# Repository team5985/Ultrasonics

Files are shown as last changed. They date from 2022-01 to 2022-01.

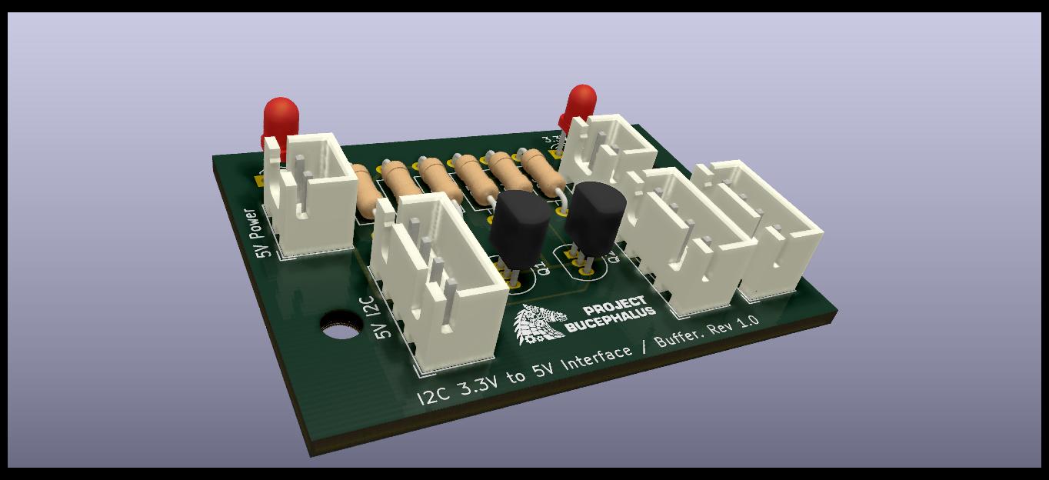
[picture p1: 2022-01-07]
I2C_Interface/V01.01/I2C_Interface.jpg

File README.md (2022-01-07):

# Ultrasonics
Ultrasonic hardware and software

This contains the design files for the ultrasonics circuit boards, as well as the software for the microcontroller.

* Hardware
These are the project files from KiCAD and include the circuit diagramme, netlist, and PCB layout. The Gerber directory
contains the final output that was sent to the PCB manufacturer to have the boards made. This should be openable as a
project from within KiCAD.

* Software
These are the project files from AVR Studio (or ATMEL Studio, or Microchip Studio) and contain the setup required to
compile, emulate and debug the microcontroller code. This should be able to be opened by AVR Studio as a project and
used immediately. The main file in this is "main.asm" which is the actual code for the microcontroller, the remaining
files are merely configuration.

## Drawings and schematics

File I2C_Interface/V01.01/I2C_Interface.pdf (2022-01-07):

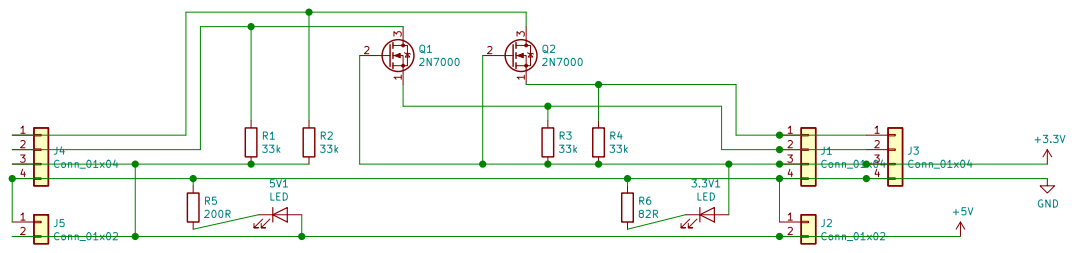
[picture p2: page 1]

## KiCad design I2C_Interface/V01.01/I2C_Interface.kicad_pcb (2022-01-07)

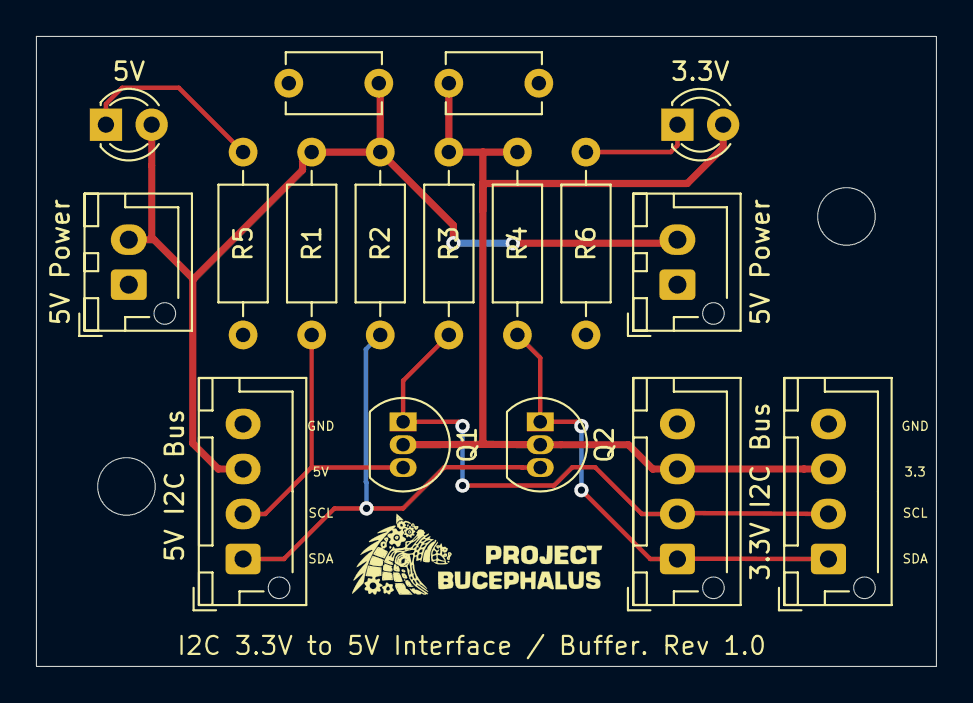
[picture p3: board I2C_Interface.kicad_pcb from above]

Board: 2 copper layers, 50.0 x 35.0 mm, 17 parts (0 on the bottom side), 9 nets.

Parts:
3.3V, 5V: LED; LED_D3.0mm
C1, C2: 4.7uF; C_Disc_D5.1mm_W3.2mm_P5.00mm
J1, J3: 3.3V I2C Bus; JST_XH_B4B-XH-AM_1x04_P2.50mm_Vertical
J2, J5: 5V Power; JST_XH_B2B-XH-AM_1x02_P2.50mm_Vertical
J4: 5V I2C Bus; JST_XH_B4B-XH-AM_1x04_P2.50mm_Vertical
Q1, Q2: 2N7000; TO-92_Inline
R1, R2, R3, R4: 33k; R_Axial_DIN0207_L6.3mm_D2.5mm_P10.16mm_Horizontal
R5: 200R; R_Axial_DIN0207_L6.3mm_D2.5mm_P10.16mm_Horizontal
R6: 82R; R_Axial_DIN0207_L6.3mm_D2.5mm_P10.16mm_Horizontal

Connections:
+3V3: 3.3V.2, C2.1, J1.3, J3.3, Q1.2, Q2.2, R3.2, R4.2
+5V: 5V.2, C1.2, J2.2, J4.3, J5.2, R1.2, R2.2
GND: C1.1, C2.2, J1.4, J2.1, J3.4, J4.4, J5.1, R5.1, R6.1
unnamed: 3.3V.1, R6.2
unnamed: 5V.1, R5.2
unnamed: J1.1, J3.1, Q2.1, R4.1
unnamed: J1.2, J3.2, Q1.1, R3.1
unnamed: J4.1, Q2.3, R2.1
unnamed: J4.2, Q1.3, R1.1

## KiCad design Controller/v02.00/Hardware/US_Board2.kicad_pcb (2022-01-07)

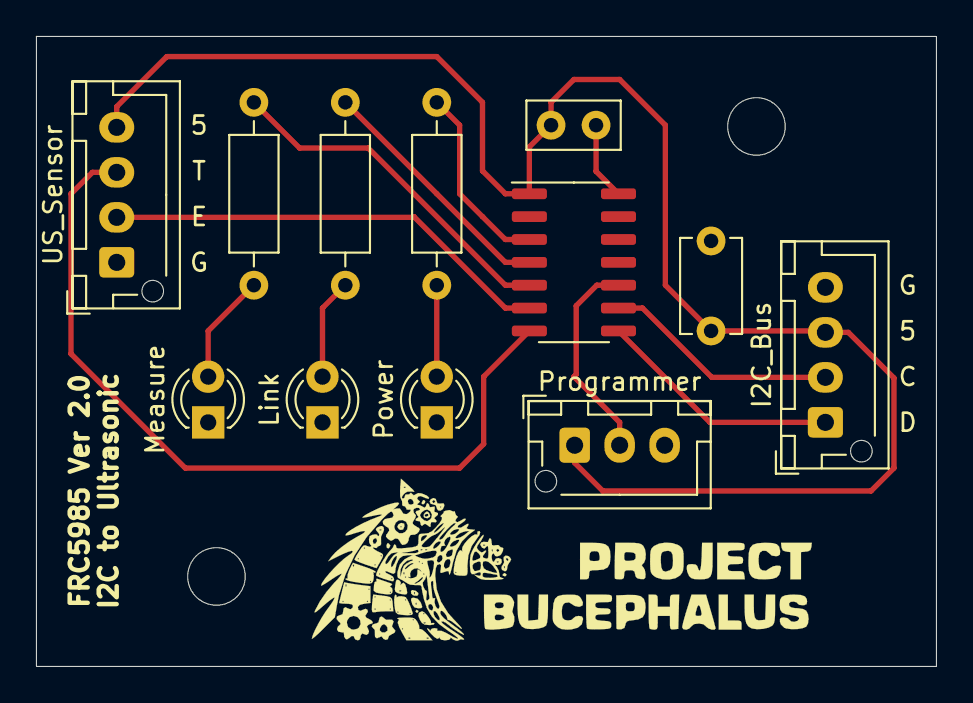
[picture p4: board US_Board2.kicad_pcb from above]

Board: 2 copper layers, 50.0 x 35.0 mm, 12 parts (0 on the bottom side), 13 nets.

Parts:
200R1, 200R2, 200R3: R; R_Axial_DIN0207_L6.3mm_D2.5mm_P10.16mm_Horizontal
C1: 4.7uF; C_Disc_D5.1mm_W3.2mm_P5.00mm
C2: 100nF; C_Disc_D5.0mm_W2.5mm_P2.50mm
I2C_Bus: Conn_01x04_Male; JST_XH_B4B-XH-AM_1x04_P2.50mm_Vertical
Link: Yellow LED; LED_D3.0mm
Measure: Green LED; LED_D3.0mm
Power: Red LED; LED_D3.0mm
Programmer: Conn_01x03; JST_XH_B3B-XH-AM_1x03_P2.50mm_Vertical
U1: ATtiny214-SS; SOIC-14_3.9x8.7mm_P1.27mm
US_Sensor: Conn_01x04_Male; JST_XH_B4B-XH-AM_1x04_P2.50mm_Vertical

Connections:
+5V: C1.1, C2.1, I2C_Bus.3, Programmer.1, U1.1, US_Sensor.4
GND: C1.2, C2.2, I2C_Bus.4, Link.1, Measure.1, Power.1, Programmer.3, U1.14, US_Sensor.1
unnamed: 200R1.1, Link.2
unnamed: 200R1.2, U1.4
unnamed: 200R2.1, Power.2
unnamed: 200R2.2, U1.3
unnamed: 200R3.1, Measure.2
unnamed: 200R3.2, U1.5
unnamed: I2C_Bus.1, U1.8
unnamed: I2C_Bus.2, U1.9
unnamed: Programmer.2, U1.10
unnamed: U1.6, US_Sensor.2
unnamed: U1.7, US_Sensor.3

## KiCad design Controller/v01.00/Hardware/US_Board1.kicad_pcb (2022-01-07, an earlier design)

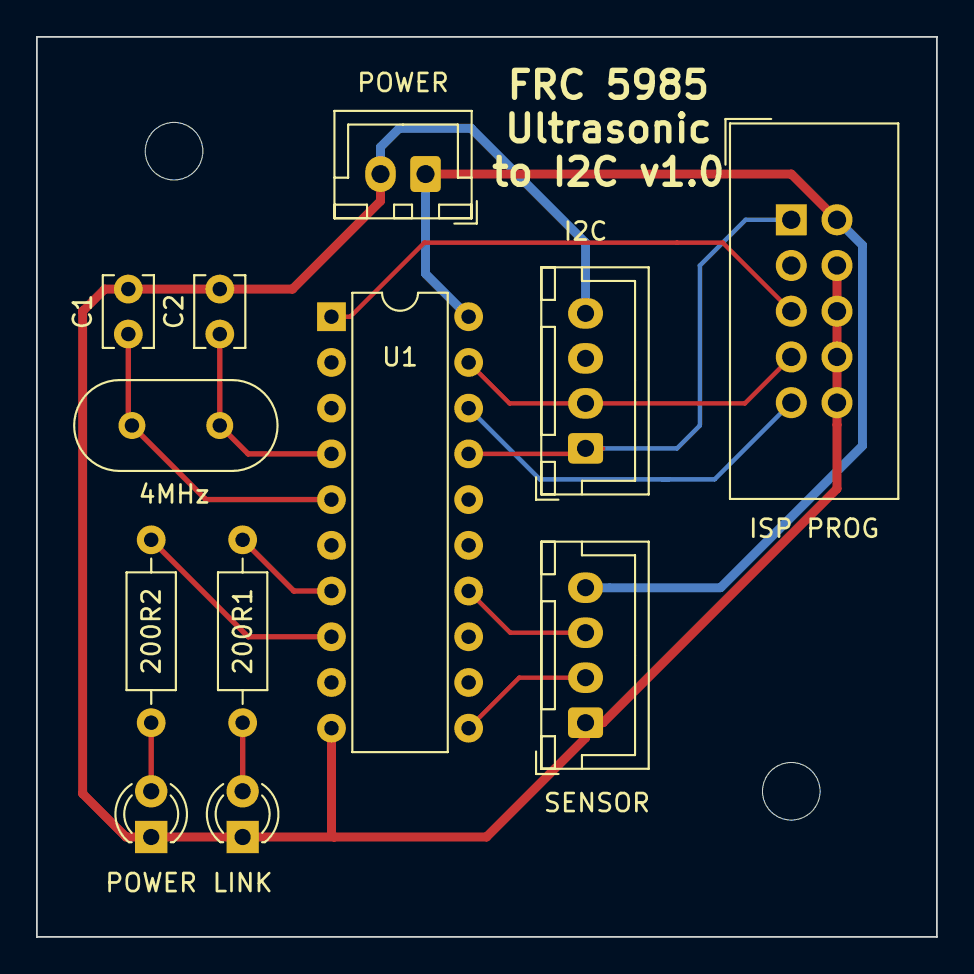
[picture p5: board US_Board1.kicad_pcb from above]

Board: 2 copper layers, 50.0 x 50.0 mm, 14 parts (0 on the bottom side), 14 nets.

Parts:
4MHz: Crystal; Crystal_HC49-U_Vertical
200R1, 200R2: R; R_Axial_DIN0207_L6.3mm_D2.5mm_P10.16mm_Horizontal
 : MountingHole_3.2mm_M3_DIN965
 #2: MountingHole_3.2mm_M3_DIN965
C1, C2: C; C_Disc_D3.8mm_W2.6mm_P2.50mm
I2C: Conn_01x04_Male; JST_XH_B4B-XH-A_1x04_P2.50mm_Vertical
ISP PROG: AVR-ISP-10; IDC-Header_2x05_P2.54mm_Vertical
LINK: Yellow LED; LED_D3.0mm
POWER: Conn_01x02_Male; JST_XH_B2B-XH-A_1x02_P2.50mm_Vertical
POWER#2: Red LED; LED_D3.0mm
SENSOR: Conn_01x04_Male; JST_XH_B4B-XH-A_1x04_P2.50mm_Vertical
U1: ATtiny2313-20PU; DIP-20_W7.62mm

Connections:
+5V: ISP PROG.2, POWER.1, SENSOR.4, U1.20
GND: C1.2, C2.2, I2C.4, ISP PROG.4, ISP PROG.6, ISP PROG.8, ISP PROG.10, LINK.1, POWER.2, POWER#2.1, SENSOR.1, U1.10
unnamed: 4MHz.1, C1.1, U1.5
unnamed: 4MHz.2, C2.1, U1.4
unnamed: 200R1.1, LINK.2
unnamed: 200R1.2, U1.7
unnamed: 200R2.1, POWER#2.2
unnamed: 200R2.2, U1.8
unnamed: I2C.1, ISP PROG.1, U1.17
unnamed: I2C.2, ISP PROG.7, U1.19
unnamed: ISP PROG.5, U1.1
unnamed: ISP PROG.9, U1.18
unnamed: SENSOR.2, U1.11
unnamed: SENSOR.3, U1.14

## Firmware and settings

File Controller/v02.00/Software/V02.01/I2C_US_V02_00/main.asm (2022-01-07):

;
; I2C_US_V02_00.asm
;
; Created: 4/02/2021 10:20:44 PM
; Author : Graham
;
; Device = ATtiny214
;
; Code for I2C to Ultrasonic interface.
; Hardware version v2.0
; (not supported on hardware version v1.0)
;
; Internal 20MHz clock is selected
; Timer A0 - Sends pulses to the ultrasonic sensor
; - Pin 7 - WO2/PB2
; Timer B0 is uses to measure the length of the returning pulses.
; - Pin 6 - PB3
; I2C interface
; - Pin 8 - SDA/PB1
; - Pin 9 - SCL/PB0
; LED Outputs
; - Pin 3 - PA5 - Red LED (Power)
; - Pin 4 - PA6 - Yellow (Comms)
; - Pin 5 - PA7 - Green (Valid Measurement)
; Overhead connections...
; - Pin 1 - VDD +5v
; - Pin 14 - GND
; - Pin 10 - UPDI programming interface
; Unused pins
; - Pin 2 - PA4
; - Pin 11 - PA1
; - Pin 12 - PA2
; - Pin 13 - PA3

.include "tn214def.inc"

; Change this address on some devices to have multiple addressable devices on a single I2C bus.
.equ MySlaveAddress	= 0x14

.equ DDR_I2C	= PORTB_DIR
.equ PORT_I2C	= PORTB_OUT
.equ PIN_I2C	= PORTB_IN
.equ SCL		= 0				;!!!!!!!!!!!!!SCL DDR and PORT are ALWAYS =1	 !!!!!!!!!!!!!!!!!
.equ SDA 		= 1				;!!!!!!!!!!!!!SDA PORT are ALWAYS =1 			!!!!!!!!!!!!!!!!!
.equ OC1A		= 3				; Output compare pin for ultrasonic trigger
.equ LED_RED	= 5
.equ LED_YELLOW	= 6
.equ LED_GREEN	= 7

.def AL = r16
.equ TCA0_WO2 = 2				; WO2 is portB pin 2

	; If we set the prescaler at /24 then we end up with 0.833MHz = 78.6ms / 65536 counts
	;	This gives 50000 counts per 60ms.
	;	The pulse needs to be on for 9 counts to be greater than 10us
.equ TCA0_PERIOD = 50000
.equ TCA0_PWMONTIME = 10

.dseg
.org	SRAM_START					;RAMTOP
I2CsubAddrBuf:	 	.byte 1

;****************************************************************************************
;----------------------------------------------------------;
.cseg
.org 0x0000
	rjmp RESET
.org CRCSCAN_NMI_vect
	rjmp ISR
.org BOD_VLM_vect
	rjmp ISR
.org PORTA_PORT_vect
	rjmp ISR
.org PORTB_PORT_vect
	rjmp ISR
.org RTC_CNT_vect
	rjmp ISR
.org RTC_PIT_vect
	rjmp ISR
.org TCA0_OVF_vect		; Also TCA0_LUNF
	rjmp TCA0_OVF_ISR
.org TCA0_HUNF_vect
	rjmp ISR
.org TCA0_LCMP0_vect		; Also TCA0_CMP0
	rjmp ISR
.org TCA0_LCMP1_vect		; Also TCA0_CMP1
	rjmp ISR
.org TCA0_LCMP2_vect		; Also TCA0_CMP2
	rjmp ISR
.org TCB0_INT_vect
	rjmp TCB0_INT_ISR
.org TCD0_OVF_vect
	rjmp ISR
.org TCD0_TRIG_vect
	rjmp ISR
.org AC0_AC_vect
	rjmp ISR
.org ADC0_RESRDY_vect
	rjmp ISR
.org ADC0_WCOMP_vect
	rjmp ISR
.org TWI0_TWIS_vect
	rjmp TWI0_TWIS_ISR
.org TWI0_TWIM_vect
	rjmp TWI0_TWIM_ISR
.org SPI0_INT_vect
	rjmp ISR
.org USART0_RXC_vect
	rjmp ISR
.org USART0_DRE_vect
	rjmp ISR
.org USART0_TXC_vect
	rjmp ISR
.org NVMCTRL_EE_vect
	rjmp ISR


RESET:

	;It is not required to initialise the stack pointer.
	;ldi r16, low(RAMEND)
	;out SPL, r16

	;set port A pins 5, 6 & 7 to outputs for the LEDs, remainder as inputs/tristate.
	ldi r16, 0x00+(1<<LED_RED)+(1<<LED_YELLOW)+(1<<LED_GREEN)
	sts PORTA_DIR, r16

	ldi r16, 0x00+(1<<LED_RED)+(0<<LED_YELLOW)+(0<<LED_GREEN)
	sts PORTA_OUT, r16

	; I2C clock line, plus PWM pin are outputs
	ldi r16, 0x00+(1<<SCL)+(1<<TCA0_WO2)
	sts PORTB_DIR, r16
	ldi r16, 0x00+(1<<SCL)+(1<<SDA)
	sts PORTB_OUT, r16

	;The analogue comparator is disabled on startup already
	;sbi ACSR,ACD					;disable analogue comparator
	
	;Not sure what to do here - need to read the manual!
	;outi MCUCR,(1<<SE)				;Sleep On///Power-Down Mode

	;This next few lines fills the first 120 bytes of the buffer used for I2C with numbers counting up.
	;It can be used for testing before the ultrasonic code is finished.
	;It will be overwritten as soon as an ultrasonic measurement is made.
	ldi XL,low(I2CsubAddrBuf)
	ldi XH,high(I2CsubAddrBuf)
	ldi r16,1
initloop1:
	st X+,r16
	inc r16
	cpi r16,120
	brlo initloop1


	;Initialise timer/counter 0
	; TCA0 will drive the hardware pin to trigger an ultrasonic measure.
	; To pulse approximately every 60ms, pulse length at least 10us
	; Also an interrupt to be generated to reset the I2C link LED

	ldi r16, CPU_CCP_IOREG_gc
	ldi r17, 0x00 + (1<<CLKCTRL_PEN_bp) + CLKCTRL_PDIV_24X_gc
	sts CPU_CCP, r16		; Unlock clock controller for change.
	sts CLKCTRL_MCLKCTRLB, r17

	; Set clock period to 50000 counts.
	ldi r16, low(TCA0_PERIOD)
	sts TCA0_SINGLE_PER, r16
	ldi r16, high(TCA0_PERIOD)
	sts TCA0_SINGLE_PER+1, r16

	;Set WO2/CMP2 on time to 10 counts
	ldi r16, low(TCA0_PWMONTIME)
	sts TCA0_SINGLE_CMP2, r16
	ldi r16, high(TCA0_PWMONTIME)
	sts TCA0_SINGLE_CMP2+1, r16

	; Enable counter in normal mode
	ldi r16, (1<<TCA_SINGLE_ENABLE_bp)
	sts TCA0_SINGLE_CTRLA, r16

	; Enable waveform on CMP2 in PWM mode
	ldi r16, (1<<TCA_SINGLE_CMP2EN_bp) + (TCA_SINGLE_WGMODE_SINGLESLOPE_gc <<TCA_SINGLE_WGMODE_gp)
	sts TCA0_SINGLE_CTRLB, r16

	; Enable overflow interrupt.
	ldi r16, (1<<TCA_SINGLE_OVF_bp)
	sts TCA0_SINGLE_INTCTRL, r16




	;Initialise timer/counter 1
	;Normal counter mode, no output compare
;	outi TCCR1A, 0
	; Clock select / 8
;	outi TCCR1B, (1<<CS11) | (1<<ICES1)
	;outi TCCR1B, (1<<CS10) | (1<<CS11)

	ldi r16, (1<<TCB_ENABLE_bp)
	sts TCB0_CTRLA, r16
	ldi r16, (1<<TCB_CCMPEN_bp) + (TCB_CNTMODE_PW_gc<<TCB_CNTMODE_gp)
	ldi r16, (TCB_CNTMODE_PW_gc<<TCB_CNTMODE_gp)
	sts TCB0_CTRLB, r16
	ldi r16, (1<<TCB_CAPTEI_bp)
	sts TCB0_EVCTRL, r16
	ldi r16, (1<<TCB_CAPT_bp)
	sts TCB0_INTCTRL, r16

	ldi r16, EVSYS_ASYNCCH1_PORTB_PIN3_gc
	sts EVSYS_ASYNCCH1, r16
	ldi r16, EVSYS_ASYNCUSER0_ASYNCCH1_gc
	sts EVSYS_ASYNCUSER0, r16


;I2Cinit:

	; Enable the TWI as an I2C slave by writing in our slave address and enabling.
	ldi r16, MySlaveAddress<<1
	sts TWI0_SADDR, r16
	ldi r16, 0x00 + (1<<TWI_ENABLE_bp) + (1<<TWI_DIEN_bp) + (1<<TWI_APIEN_bp) + (1<<TWI_PIEN_bp) + (1<<TWI_SMEN_bp)
	sts TWI0_SCTRLA, r16

	sei

MainLoop:
;	sleep
;	WDR
	rjmp MainLoop


; TWI slave interrupt
; if APIF (address or stop) bit on
;	if AP is on (address interrupt)
;		if R/W bit is off (write)
;		- remember write mode
;		- reset APIF flag
;		- return
;		else (read)
;		- remember read mode
;		- initialise read pointer
;		- reset APIF flag
;		- return
;	else (STOP command)
;	- reset all read / write flags
; else if DIF is on (data transaction complete)
;	if reading
;	- get next byte & increment pointer
;	- write byte
;	- clear DIF flag
;	- return
;	else (writing)
;	- read and discard byte
;	- clear DIF flag
;	- return
TWI0_TWIS_ISR:
	cli
	lds r17, TWI0_SSTATUS
	sbrs r17, TWI_APIF_bp
	rjmp TWI0_NO_APIF
	; APIF flag is on (address or stop interrupt)
	sbrs r17, TWI_AP_bp
	rjmp TWI0_STOP
	; AP flag is on (address interrupt)
	lds r17, TWI0_SDATA
	sbrc r17, 0
	rjmp TWI0_READ
	; Address received was for write
	sbr r18, 0b00000010		; Remember write
	ldi r17, 0x03<<TWI_SCMD_gp
	sts TWI0_SCTRLB, r17	; Command - acknowledge & read next byte
	ldi r17, 1<<TWI_APIF_bp
	sts TWI0_SSTATUS, r17	; clear interrupt flag
	sei
	reti

TWI0_READ:
	sbr r18, 0b00000001		; Remember read

	; Create message
	ldi YL, 1
	sts I2CsubAddrBuf, YL
	mov YL, r10
	sts I2CsubAddrBuf+1, YL
	mov YL, r8
	sts I2CsubAddrBuf+2, YL
	mov YL, r9
	sts I2CsubAddrBuf+3, YL
	mov YL, r10
	eor YL, r8
	eor YL, r9
	sts I2CsubAddrBuf+4, YL


	ldi r19, 0x01			; initialise pointer
	sts I2CsubAddrBuf, r19
	ldi r17, 0x03<<TWI_SCMD_gp
	sts TWI0_SCTRLB, r17	; Command - acknowledge & generate data interrupt for first byte
	ldi r17, 1<<TWI_APIF_bp
	sts TWI0_SSTATUS, r17	; clear interrupt flag

	; Turn yellow LED on for Rx indication
	ldi r20, 4
	ldi r16, (1<<LED_YELLOW)
	sts PORTA_OUTSET, r16
	sei
	reti

TWI0_STOP:
	ldi r18, 0b00000000		; clear read/write flags
	ldi r17, 1<<TWI_APIF_bp
	sts TWI0_SSTATUS, r17	; clear interrupt flag
	sei
	reti

TWI0_NO_APIF:
	sbrc r18,0
	rjmp TWI0_DATAR
	sbrc r18,1
	rjmp TWI0_DATAW
	lds r17, TWI0_SDATA
	; data interrupt when we are not reading or writing - turn on yellow LED
	ldi r16, (1<<LED_YELLOW)
	sts PORTA_OUTSET, r16
	sei
	reti

TWI0_DATAR:
	lds YL,I2CsubAddrBuf
	clr YH
	;addiw Y,SRAM_START
    subi    YL,low(-(SRAM_START))
    sbci    YH,high(-(SRAM_START))

	ld r16,Y+
	sts TWI0_SDATA,r16
	;subiw Y,SRAM_START
    subi    YL,low(SRAM_START)
    sbci    YH,high(SRAM_START)
	
	sts I2CsubAddrBuf,YL
	sei
	reti

TWI0_DATAW:
	; Ignore all writes!
	lds r17, TWI0_SDATA
	sei
	reti



	ldi r16, (1<<LED_YELLOW)
	sts PORTA_OUTSET, r16



TWI0_TWIM_ISR:
	reti

TCA0_OVF_ISR:
	cli
	; Clear TCA interrupt flag.
	ldi r21, (1<<TCA_SINGLE_OVF_bp)
	sts TCA0_SINGLE_INTFLAGS, r21
	; Turn off yellow LED if no messages recently.	
	dec r20
	brne YLEDLit
	ldi r21, (1<<LED_YELLOW)
	sts PORTA_OUTCLR, r21
YLEDLit:
	; Turn off green LED if no measurements last tick.	
	dec r22
	brne GLEDLit
	ldi r21, (1<<LED_GREEN)
	sts PORTA_OUTCLR, r21
	ldi r21, 0
	mov r8, r21
	mov r9, r21
GLEDLit:
	; r23 will be zero if sensor feedback bit is off.
	; r23 will be one if sensor feedback bit is on and green LED is turned off.
	; PB3 is the bit
	lds r21, PORTB_IN
	sbrs r21, 3
	rjmp FBOff
FBOn:
	ldi r23,2
	ldi r21, (1<<LED_GREEN)
	sts PORTA_OUTCLR, r21
	ldi r21, 0
	mov r8, r21
	mov r9, r21
	rjmp FBEnd
FBOff:
	cpi r23, 0
	breq FBEnd
	dec r23
FBEnd:
	sei
	reti

TCB0_INT_ISR:
; Check if input was off when pulse was last run. If on, then ignore reading and return immediately.
	cli
	cpi r23, 0
	breq GoodMeas
	; Read data to clear interrupt.
	lds r21, TCB0_CCMPL
	lds r21, TCB0_CCMPH
	sei
	reti
GoodMeas:
	ldi r21, (1<<LED_GREEN)
	sts PORTA_OUTSET, r21
	ldi r22, 2
	; Must read low before high when reading 16 bit register.
	lds r8, TCB0_CCMPL
	lds r9, TCB0_CCMPH
	inc r10
	sei
	reti

ISR:
	reti
